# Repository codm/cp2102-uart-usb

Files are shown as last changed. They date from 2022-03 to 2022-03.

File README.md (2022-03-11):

# cod.m CP2102N USB UART

---

___Waiting for PCB's! Not yet tested!___

---

This is a reimplementation of [Watterott's CP2102N Breakout](https://learn.watterott.com/breakouts/cp2102n-breakout/) which is licensed under CC-BY-SA.
Based on Silabs CP2102N with integrated voltage regulator for the 3.3V rail.

Never did an own USB UART adapter and wanted to implement USB-C connectors. So I took this oportunity.

Here's a 3D Version for your viewing pleasure: https://a360.co/3vfPNpy

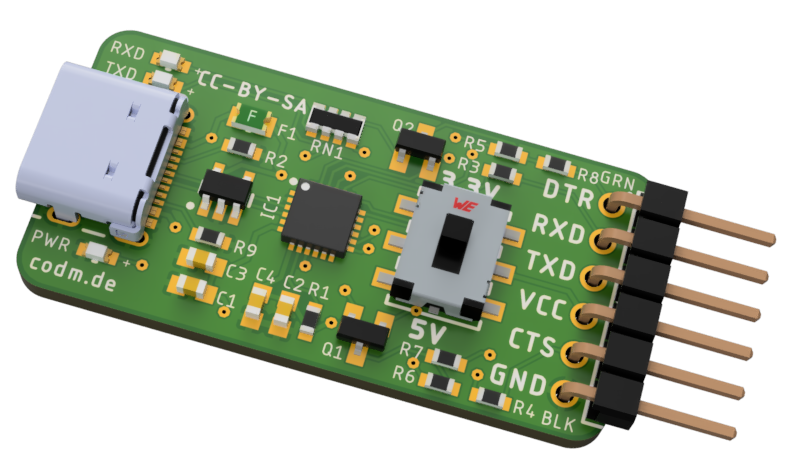
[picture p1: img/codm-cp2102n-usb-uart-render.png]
cod.m CP2102N USB UART


## Features
* USB-C (USB 2.0) connector
* Only 0603 parts, no 0402
* RTS/DSR available as solderpads
* Bigger 3.3V/5V switch
* Power LED

## Features derived from Watterott
* 500mA Polyfuse
* TVS-Diode for USB
* TX/RX LED
* Switchable logic voltage
  * Max 450mA @ 5V, 80mA @ 3.3V
  * Input low level: <= 0.6V
  * Input high level: >= 2.7V

# Thanks
* @watterott CP2102N-Breakout https://github.com/watterott/CP2102N-Breakout
* @AislerHQ for the prototype PCB's

# License
[CC-BY-SA 4.0](https://creativecommons.org/licenses/by-sa/4.0/)

cod.m GmbH, Patrik Mayer, 2022

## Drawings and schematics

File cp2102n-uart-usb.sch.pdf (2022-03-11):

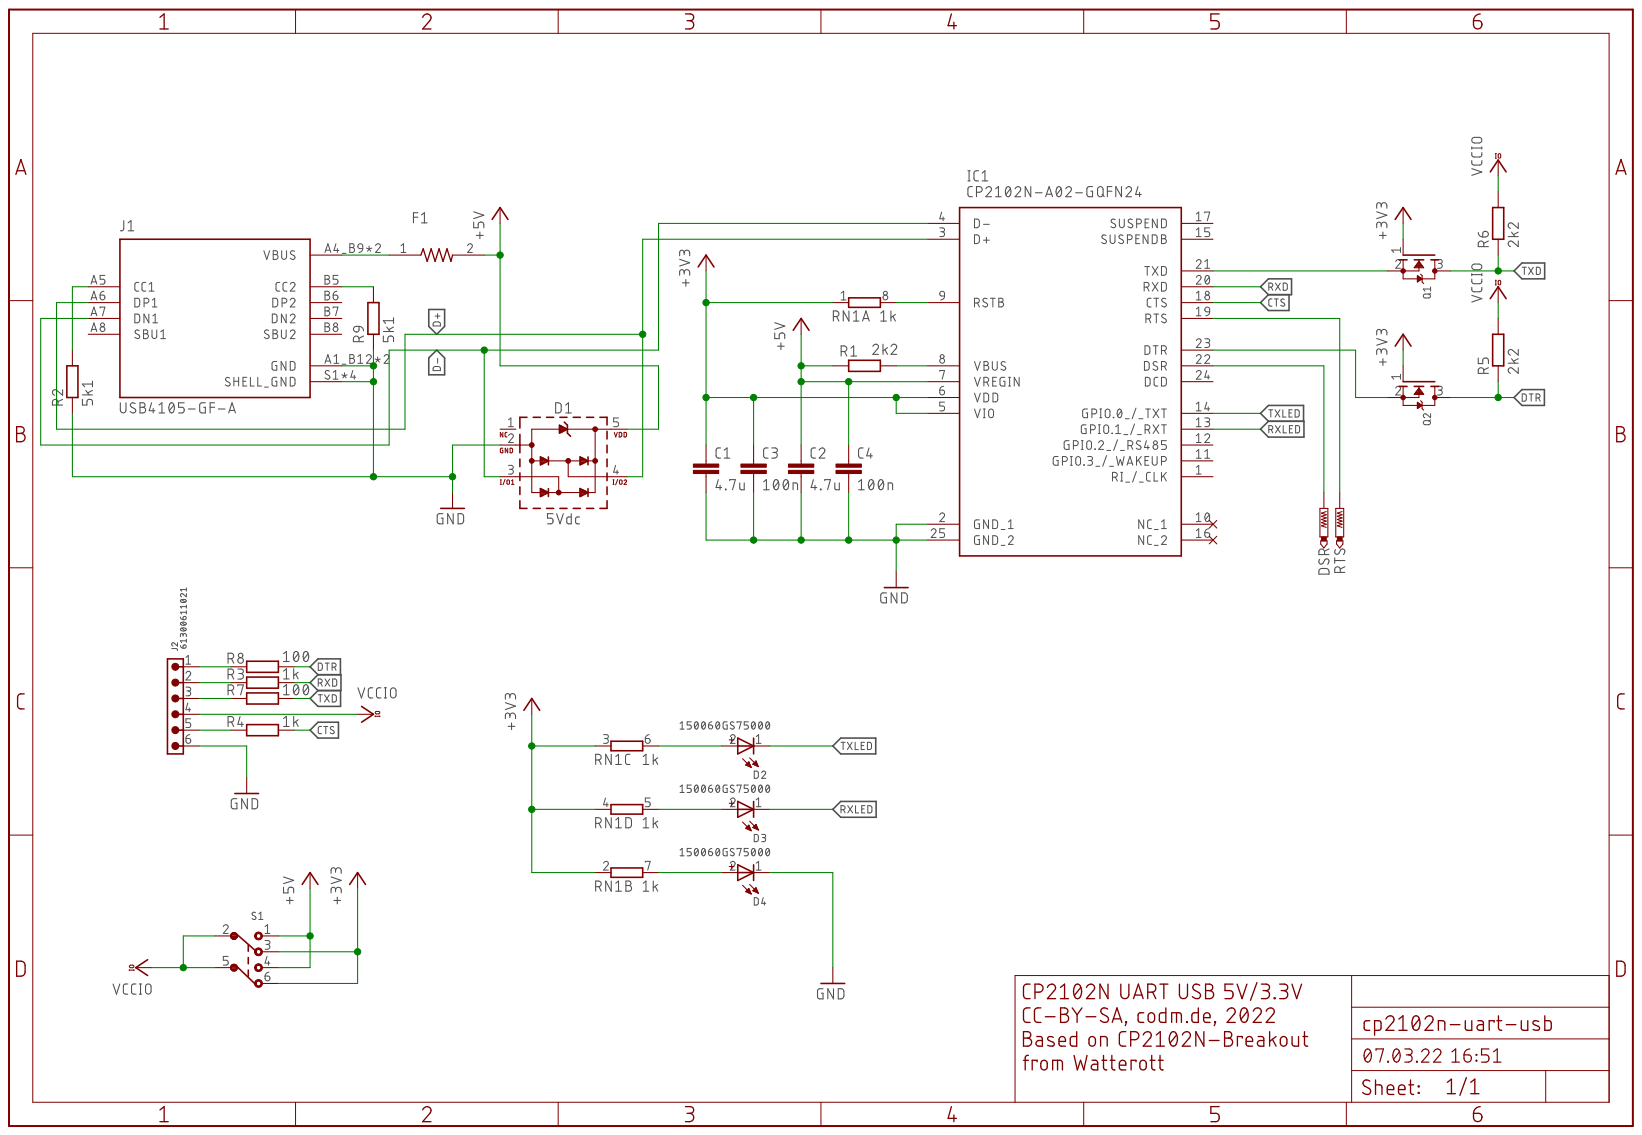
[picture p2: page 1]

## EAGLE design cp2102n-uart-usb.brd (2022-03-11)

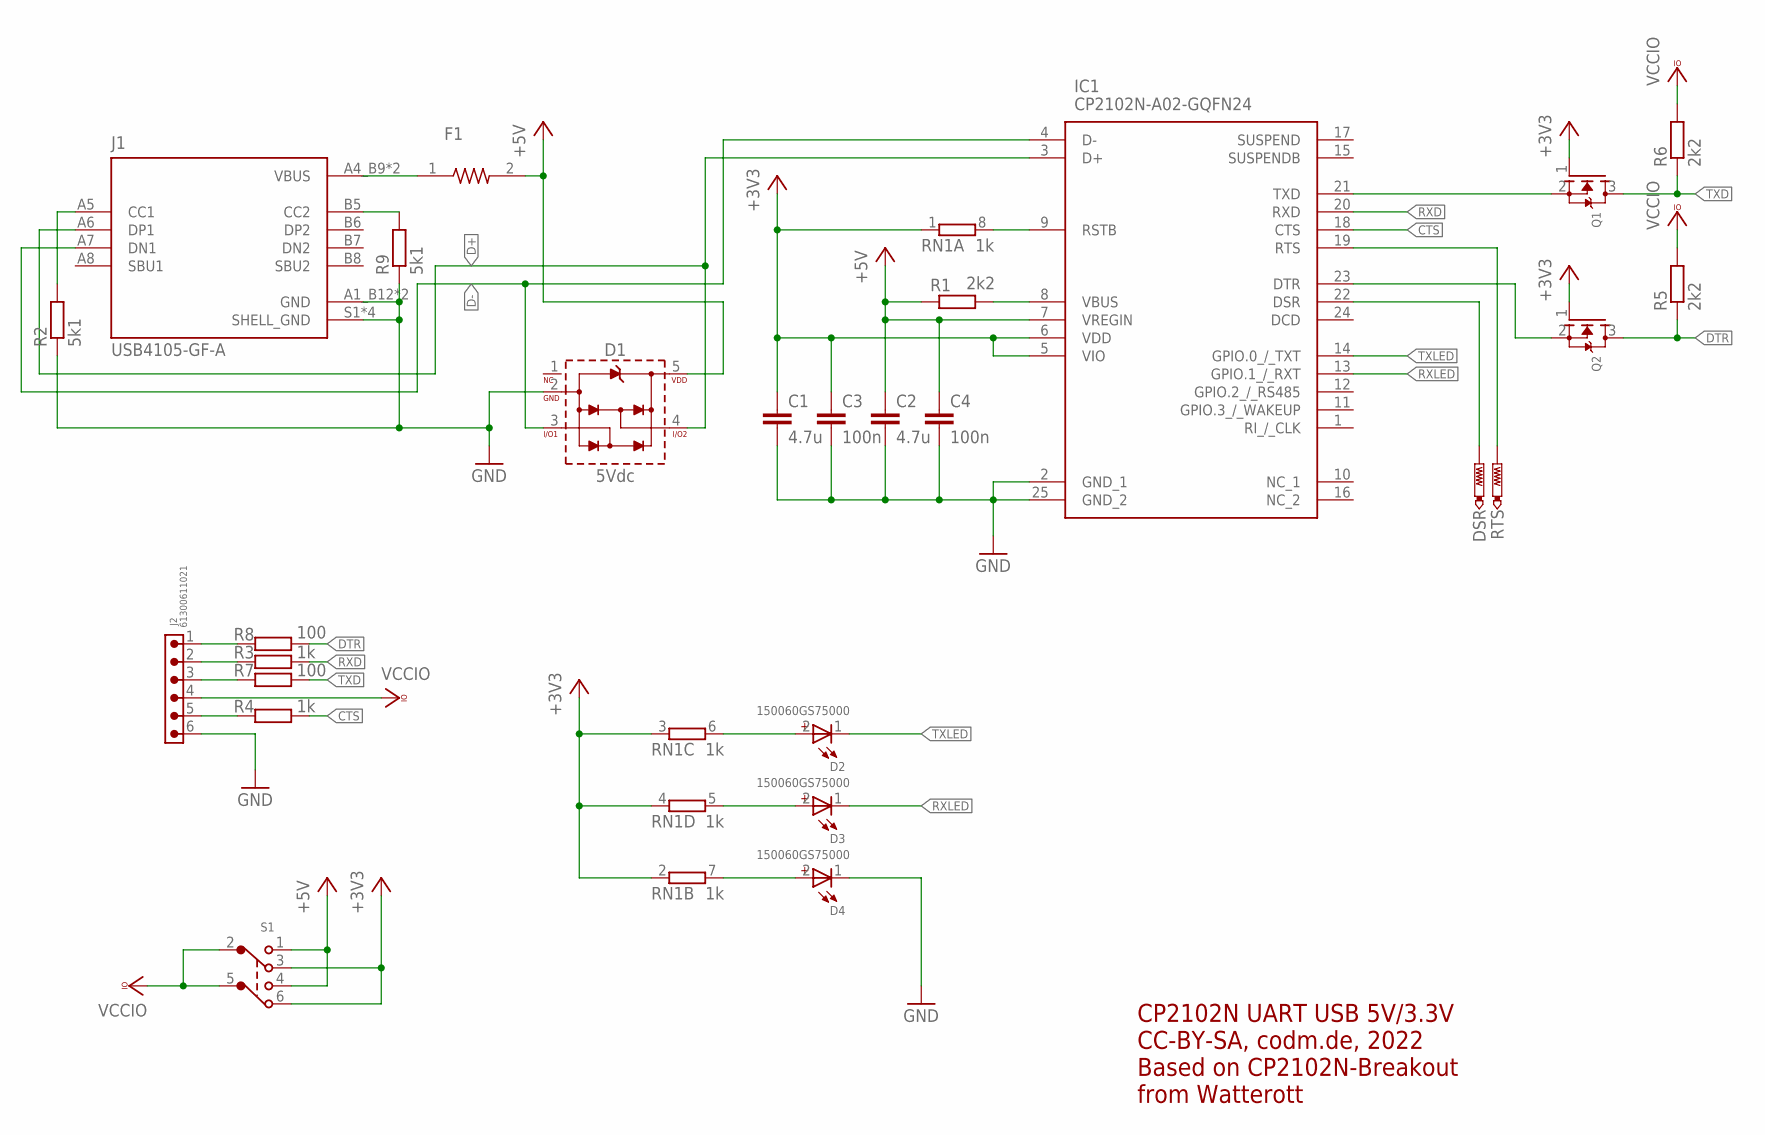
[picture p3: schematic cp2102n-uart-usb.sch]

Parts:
C1, C2: 4.7u; C0603K
C3, C4: 100n; C0603K
D1: 5Vdc; WE-TVS_SOT23-5L
D2, D3, D4: 150060GS75000; WL-SMCW_0603
DSR: PTR1B2,54; B2,54
F1: PICOSMDC050S-2; RESC2012X65N
IC1: CP2102N-A02-GQFN24; QFN50P400X400X80-25N
J1: USB4105-GF-A; GCT_USB4105-GF-A
J2: 61300611021
Q1, Q2: MOSFET-NREFLOW; SOT23
R1, R5, R6: 2k2; R0603RF
R2, R9: 5k1; R0603RF
R3, R4: 1k; R0603RF
R7, R8: 100; R0603RF
RN1: 1k; EXB38V
RTS: PTR1B2,54; B2,54
S1: 452403012014

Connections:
+3V3: C1.1, C3.1, IC1.5 (VIO), IC1.6 (VDD), Q1.1 (G), Q2.1 (G), RN1.1, RN1.2 (1), RN1.3 (1), RN1.4 (1), S1.3, S1.6
+5V: C2.1, C4.1, D1.5 (VDD), F1.2, IC1.7 (VREGIN), R1.1, S1.1, S1.4
CTS: IC1.18 (CTS), R4.2
D+: D1.4 (I/O2), IC1.3 (D+), J1.A6 (DP1)
D-: D1.3 (I/O1), IC1.4 (D-), J1.A7 (DN1)
DTR: Q2.3 (D), R5.1, R8.2
GND: C1.2, C2.2, C3.2, C4.2, D1.2 (GND), D4.1 (-), IC1.2 (GND_1), IC1.25 (GND_2), J1.A1_B12 (GND), J1.B1_A12 (GND), J1.S1 (SHELL_GND), J1.S2 (SHELL_GND), J1.S3 (SHELL_GND), J1.S4 (SHELL_GND), J2.6, R2.1, R9.1
unnamed: J1.A5 (CC1), R2.2
unnamed: D3.2 (+), RN1.5 (2)
unnamed: IC1.19 (RTS), RTS.TP
unnamed: D2.2 (+), RN1.6 (2)
unnamed: J1.B5 (CC2), R9.2
unnamed: DSR.TP, IC1.22 (DSR)
unnamed: F1.1, J1.A4_B9 (VBUS), J1.B4_A9 (VBUS)
unnamed: IC1.21 (TXD), Q1.2 (S)
unnamed: IC1.23 (DTR), Q2.2 (S)
unnamed: J2.1, R8.1
unnamed: J2.2, R3.1
unnamed: J2.3, R7.1
unnamed: J2.5, R4.1
unnamed: D4.2 (+), RN1.7 (2)
RSTB: IC1.9 (RSTB), RN1.8 (2)
RXD: IC1.20 (RXD), R3.2
RXLED: D3.1 (-), IC1.13 (GPIO.1_/_RXT)
TXD: Q1.3 (D), R6.1, R7.2
TXLED: D2.1 (-), IC1.14 (GPIO.0_/_TXT)
VBUS: IC1.8 (VBUS), R1.2
VCCIO: J2.4, R5.2, R6.2, S1.2, S1.5

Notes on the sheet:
CP2102N UART USB 5V/3.3V CC-BY-SA, codm.de, 2022 Based on CP2102N-Breakout from Watterott

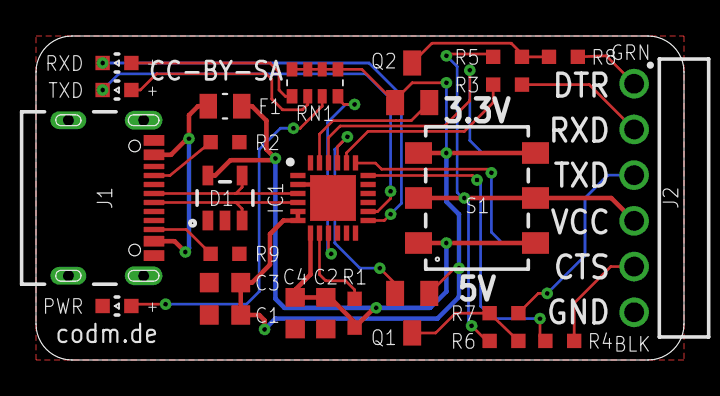
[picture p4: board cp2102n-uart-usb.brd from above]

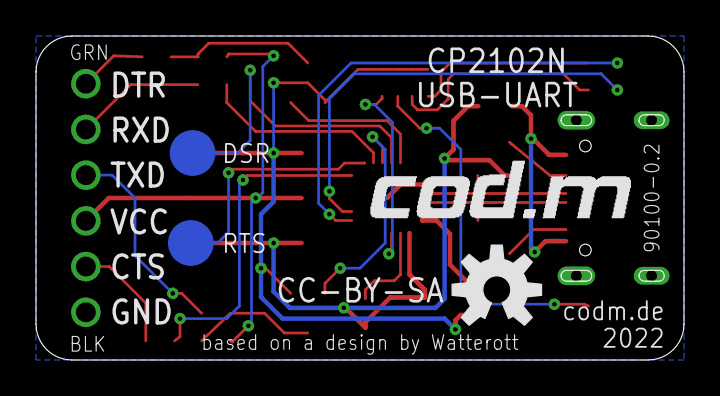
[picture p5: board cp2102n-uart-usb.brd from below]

Board: 2 copper layers, 36.0 x 18.0 mm, 29 parts (4 on the bottom side), 28 nets.

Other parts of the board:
U$1: CODM-LOGO
U$2: OSHW-LOGO-M

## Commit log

2022-02-28 first version, prototype ordered
    [cp2102n-uart-usb.brd, cp2102n-uart-usb.sch]
2022-03-11 added 5k1 to CC2
    [cp2102n-uart-usb.brd, cp2102n-uart-usb.sch]
2022-03-11 added schematic pdf

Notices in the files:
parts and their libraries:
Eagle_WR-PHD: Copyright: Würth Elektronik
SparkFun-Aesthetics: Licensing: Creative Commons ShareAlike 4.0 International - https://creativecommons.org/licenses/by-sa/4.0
